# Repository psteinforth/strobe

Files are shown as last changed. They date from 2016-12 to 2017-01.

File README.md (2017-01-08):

# strobe
ATtiny microcontroller project to control a cheap stroboscope or similar device. 

### Introduction
This piece of software was designed to enable a cheap LED stroboscope by people on a danceflor. The strobe flashes as long as it is powered. The idea was to enable the strobe for a fixed time period as soon as a dancer presses a red push-button. To avoid nearly continuous flashing due to drunken people :dancers: the strobe can not be reenabled before a configurable time period passed.

### Features
- Based on Atmel ATtiny 44A-PU microcontroller.
- Interrupt-driven recognition of push-button presses.
- Strobe activity time period is configurable by a potentiometer.
- Time period between two strobe activites is potentiometer controllable.
- Status LED for "push button active/ strobe can be enabled" and "strobe active".
- Automatic reset in case of a microcontroller hang-up by watchdog timer within 0.125 seconds.

### Details
- Some options are configurable by **preprocessor defines**. Default values will be used if they are not given. Meaning of preprocessor defines can be found in source code comments.
- Program sequence is controlled by a **Finite State Machine**
    - Legend (0 = no/not required, 1 = yes/required, -1 = unspecified/don't care)
        - buzzer_enabled (output): push-button is active and can enable the strobe
        - relais_enabled (output): relais is active and powers the strobe
        - buzzer_pressed (input): push-button was pressed
        - timer_counting (input): timer is active (strobe active or buzzer locked and time is not over)
        - next_state: new state that will be selected if all inputs met the current state
    - State transition matrix:

State | Name | buzzer_enabled | relais_enabled | buzzer_pressed | timer_counting | next_state
------|------|----------------|----------------|----------------|----------------|------------
S_0 | WAIT_FOR_KEYPRESS | 1 | 0 | 1 | -1 | BLINKING
S_1 | BLINKING | 0 | 1 | -1 | 0 | BUZZER_LOCKED
S_2 | BUZZER_LOCKED | 0 | 0 | -1 | 0 | WAIT_FOR_KEYPRESS

State transition diagram (arrows are labeled with inputs that are required for state change):
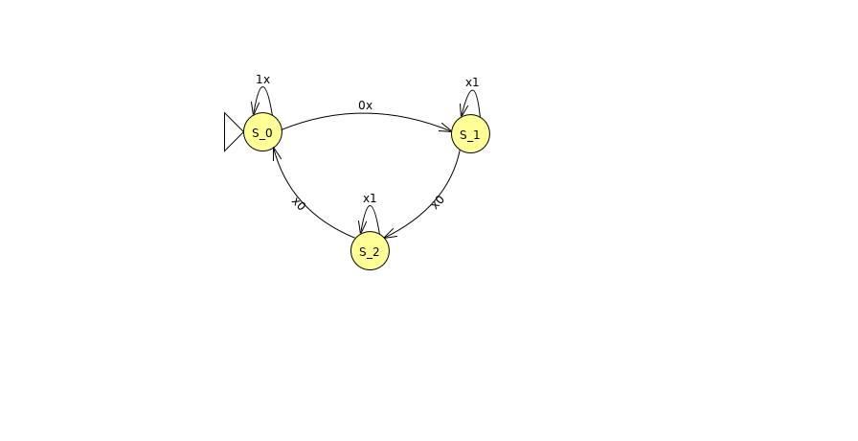
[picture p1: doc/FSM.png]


- All **time periods** are counted  by 16-bit Timer/Counter 1
- **Push-putton** presses are detected by external interrupt INT0
- **Potentiometers** are sampled by analog/digital converter (ADC)
    - Sampling is conducted only once after each power on/reset. So the adjustment of potentiometers is not detected until next microcontroller reset/restart.
    - This program does not use the low noise mode while sampling potentiometer values. However for better sampling results an averaged value of several (configurable by preprocessor define) samplings is calculated. In addition for every potentiometer an additional sampling is done first to stabilize the ADC, the value of this conversion is thrown.
- The circuit should be **power**ed with 5 V (DC). In other cases maybe other and/or additional components are required. It's recommended to enable the brown-out detector to reset the microcontroller if the current falls below a certain level (maybe 4.3 V).

### Microcontroller connections
Legend:
- *Italic* pins are required for In-System-Programming (ISP) via SPI. Pins printed grey additonally are only required for ISP.
- AREF is not connected but maybe will be used for more precise potentiometer values later. 
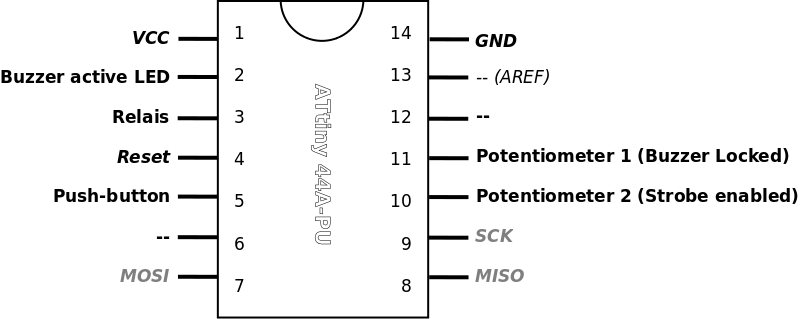
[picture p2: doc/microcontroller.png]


### Circuit Diagram
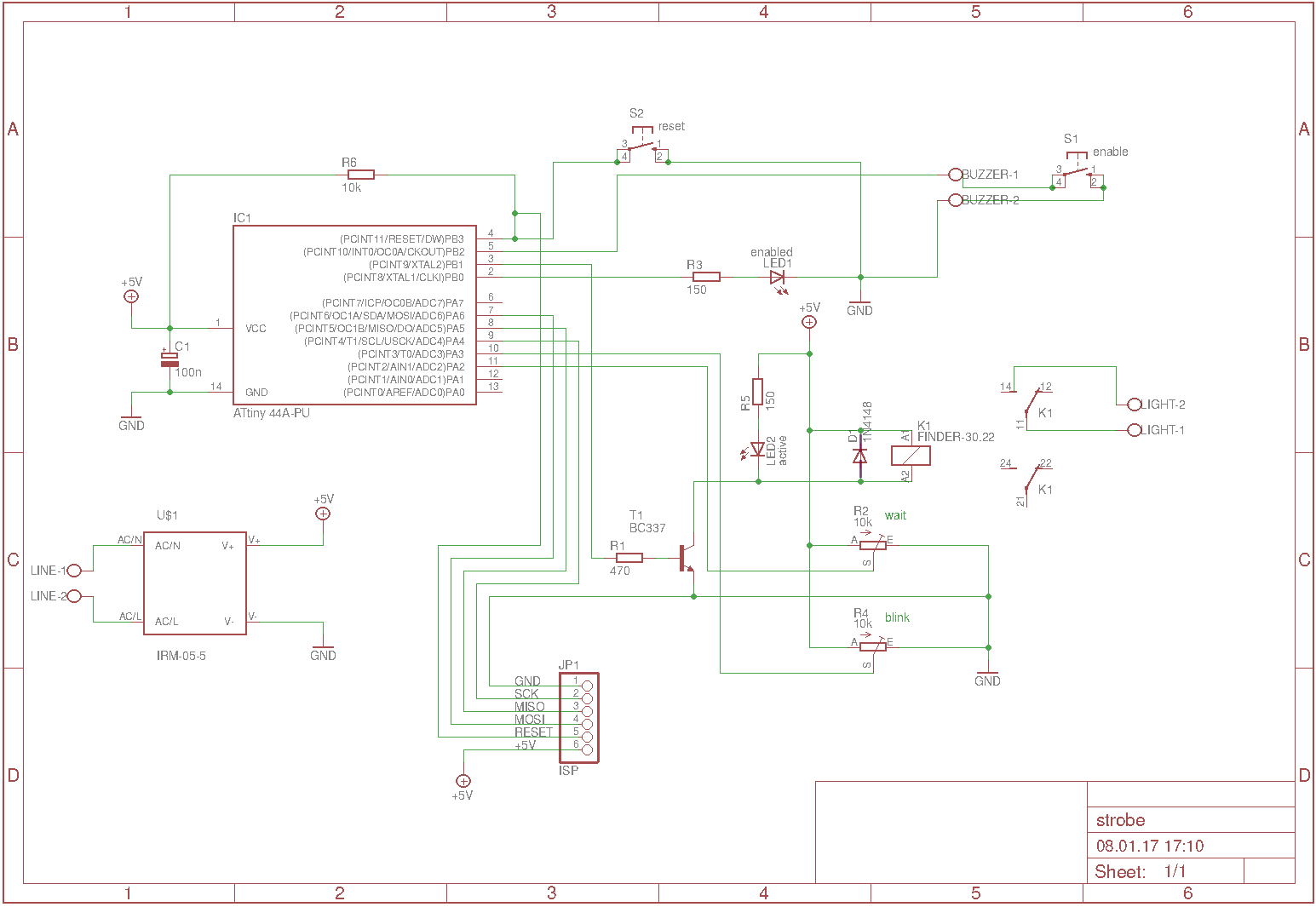
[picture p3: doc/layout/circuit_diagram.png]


### Conductor board example
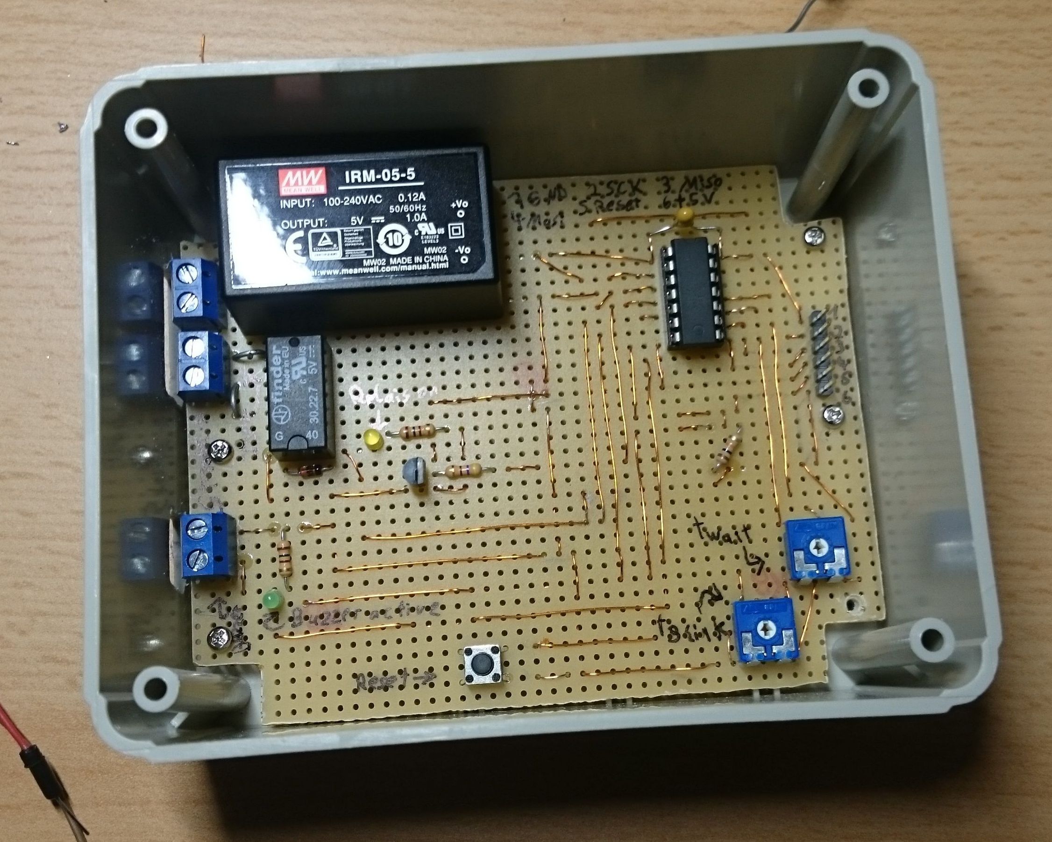
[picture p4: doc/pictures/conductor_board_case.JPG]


### Known issues
- __External Interrupt enabled unintentional.__
Under some circumstances (noisy environments) the external interrupt is triggered by electrical interferences. This maybe could be solved by implementing a debouncing algorithm to detect button presses and/or additonal hardware like external pull up resistors, a low pass filter or capacitors at the right place.

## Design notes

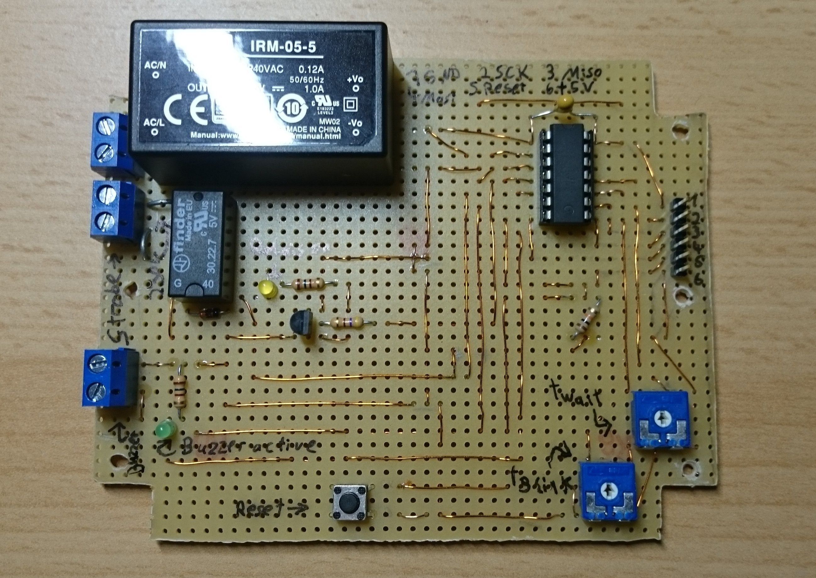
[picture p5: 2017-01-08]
doc/pictures/conductor_board.JPG

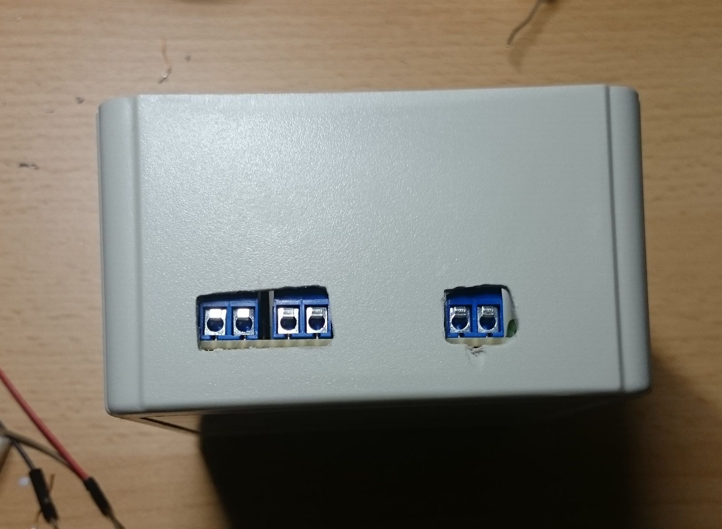
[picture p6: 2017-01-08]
doc/pictures/case_with_screw_terminals.JPG

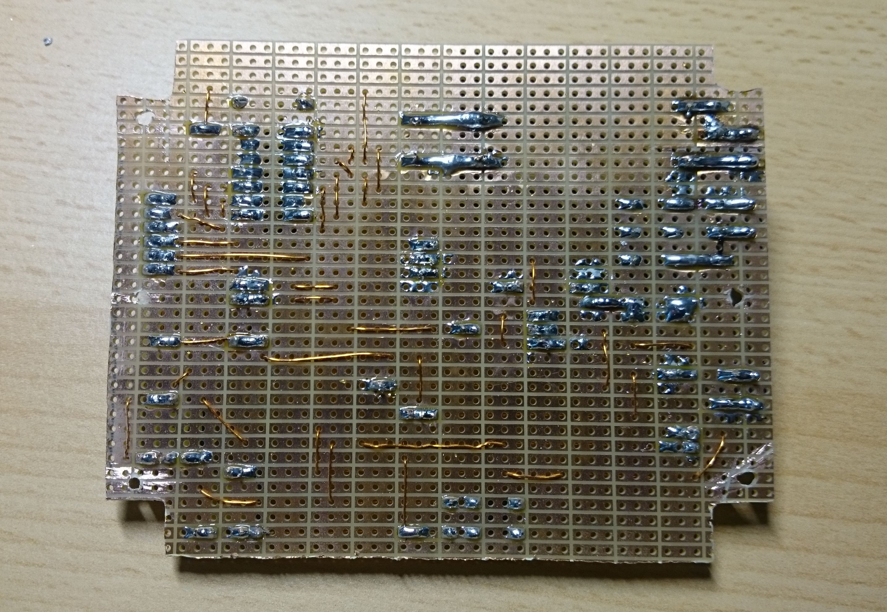
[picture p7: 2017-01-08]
doc/pictures/conductor_board_top_down.JPG

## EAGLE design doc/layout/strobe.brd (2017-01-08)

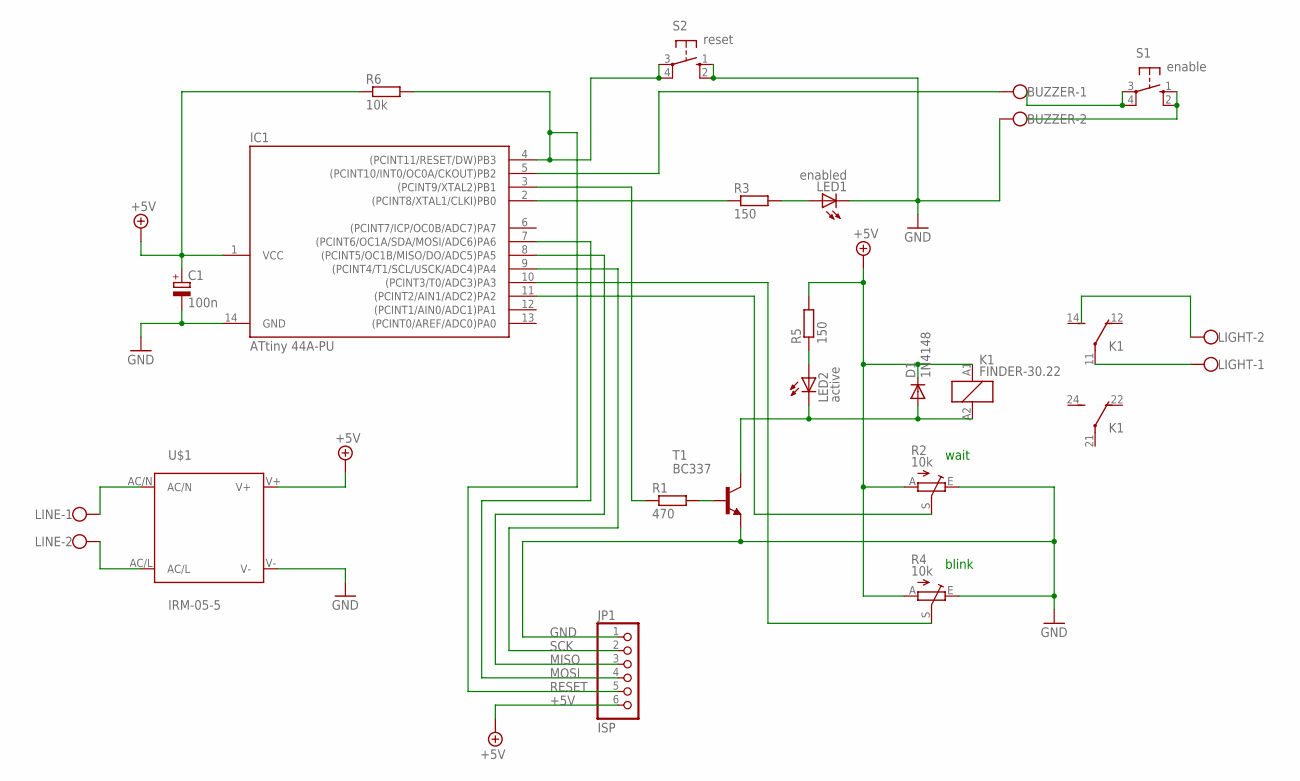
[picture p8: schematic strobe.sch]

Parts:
BUZZER: W237-102
C1: 100n; E2,5-6E
D1: 1N4148; DO35-7
IC1: ATtiny 44A-PU; DIL14
JP1: ISP; 1X06
K1: FINDER-30.22
LED1: enabled; LED3MM
LED2: active; LED3MM
LIGHT: W237-102
LINE: W237-102
R1: 470; 0207/10
R2, R4: 10k; CA6V
R3, R5: 150; 0207/10
R6: 10k; 0207/10
S1: enable; B3F-10XX
S2: reset; B3F-10XX
T1: BC337; TO92
U$1: IRM-05-5; IRM_05/10

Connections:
+5V: C1.+, D1.C, IC1.1 (VCC), JP1.6, K1.A1 (1), R2.A, R4.A, R5.2, R6.1
GND: BUZZER.2, C1.-, IC1.14 (GND), JP1.1, LED1.K (C), R2.E, R4.E, S2.1 (S), S2.2 (S1), T1.1 (E), U$1.V-
MISO: IC1.8 ((PCINT5/OC1B/MISO/DO/ADC5)PA5), JP1.3
MOSI: IC1.7 ((PCINT6/OC1A/SDA/MOSI/ADC6)PA6), JP1.4
unnamed: LINE.1, U$1.AC/N
unnamed: IC1.3 ((PCINT9/XTAL2)PB1), R1.1
unnamed: R1.2, T1.2 (B)
unnamed: IC1.11 ((PCINT2/AIN1/ADC2)PA2), R2.S
unnamed: IC1.10 ((PCINT3/T0/ADC3)PA3), R4.S
unnamed: D1.A, K1.A2 (2), LED2.K (C), T1.3 (C)
unnamed: LED1.A, R3.2
unnamed: IC1.2 ((PCINT8/XTAL1/CLKI)PB0), R3.1
unnamed: BUZZER.1, IC1.5 ((PCINT10/INT0/OC0A/CKOUT)PB2)
unnamed: K1.11, LIGHT.1
unnamed: LED2.A, R5.1
unnamed: S1.1 (S), S1.2 (S1)
unnamed: S1.3, S1.4 (P1)
RESET: IC1.4 ((PCINT11/RESET/DW)PB3), JP1.5, R6.2, S2.3, S2.4 (P1)
SCK: IC1.9 ((PCINT4/T1/SCL/USCK/ADC4)PA4), JP1.2

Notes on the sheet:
blink
wait

Board: 2 copper layers, 20 parts (0 on the bottom side), 19 nets, no tracks yet.

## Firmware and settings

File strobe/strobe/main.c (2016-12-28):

/*
 * main.c
 *
 * Created: 22.12.2016 19:00:13
 * Author : Patrick Steinforth (dev@steinforth.eu)
 */ 

#include <avr/io.h>
#include <avr/interrupt.h>
#include <inttypes.h> //int8_t and similar datatypes
#include <avr/wdt.h> //watchdog

#ifndef F_CPU
/* Define CPU frequency F_CPU if F_CPU was not already defined 
   (e.g. by command line parameter for compiler within 
   a Makefile). Warn if no frequency was passed by parameter. */
#warning "F_CPU was not defined and will be set to 1MHz"
#define F_CPU 1000000UL     /* Internal oscillator with 1.0000 MHz (prescaled by 8) */
#endif

#ifndef F_TIMER_INT
/* Define how often Timer1 Interrupt service routine is called 
   (e.g. by command line parameter for compiler within 
   a Makefile). Warn if no frequency was passed by parameter. */
#warning "F_TIMER_INT was not defined and will be set to 256"
#define F_TIMER_INT 256UL     /* Interrupt called every 1000/F_TIMER_INT= x milliseconds */
#endif
#if F_TIMER_INT > 256
#error "F_TIMER_INT must be in the range between 1 and 256 because we use a 8 bit variable."
#endif
#if F_TIMER_INT < 1
#error "F_TIMER_INT must be in the range between 1 and 256 because we use a 8 bit variable."
#endif

#ifndef TIMER_PRESCALER
/* Set hardware prescaler of timer 
   (e.g. by command line parameter for compiler within 
   a Makefile). Warn if no prescaler was passed by parameter. 
   Value has to match the timer/counter configuration. */
#warning "TIMER_PRESCALER was not defined and will be set to 1"
#define TIMER_PRESCALER 1UL     /* Timer counts every TIMER_PRESCALER clock cycle */
#endif

#ifndef ADC_AVERAGE_STEPS
/* Define from how much analog digital conversions the average will be calculated. */
#warning "ADC_AVERAGE_STEPS was not defined and will be set to 3"
#define ADC_AVERAGE_STEPS 3
#endif
#if ADC_AVERAGE_STEPS > 31
#error "ADC_AVERAGE_STEPS must be in the range between 1 and 31 so we can use one single 8 bit variable for all ADC[1:7] pins."
#endif
#if ADC_AVERAGE_STEPS < 1
#error "ADC_AVERAGE_STEPS must be in the range between 1 and 31 so we can use one single 8 bit variable for all ADC[1:7] pins."
#endif

#ifndef MAX_BLINKING_TIME
/* Define the maximum blinking time in seconds. This value will be set if potentiometer is in maximum position. */
#warning "MAX_BLINKING_TIME was not defined and will be set to 20"
#define MAX_BLINKING_TIME 20
#endif
#if MAX_BLINKING_TIME > 255
#error "MAX_BLINKING_TIME must be in the range between 1 and 255."
#endif
#if MAX_BLINKING_TIME < 1
#error "MAX_BLINKING_TIME must be in the range between 1 and 255."
#endif

#ifndef MAX_BUZZER_LOCKED_TIME
/* Define the maximum buzzer blocking time in TENs of seconds. This value will be set if potentiometer is in maximum position. 
Example: A value of 37 results in a lock time of 37*10=370 seconds = 5 minutes 10 seconds*/
#warning "MAX_BUZZER_LOCKED_TIME was not defined and will be set to 2"
#define MAX_BUZZER_LOCKED_TIME 2
#endif
#if MAX_BUZZER_LOCKED_TIME > 255
#error "MAX_BUZZER_LOCKED_TIME must be in the range between 1 and 255."
#endif
#if MAX_BUZZER_LOCKED_TIME < 1
#error "MAX_BUZZER_LOCKED_TIME must be in the range between 1 and 255."
#endif

#ifndef MAX_BUZZER_LOCKED_ADJUSTMENT
/* Define the maximum time range by which the buzzer lock time can be adjusted with potentiometer
 in TENs of seconds. If MAX_BUZZER_LOCKED_TIME is greater than MAX_BUZZER_LOCKED_ADJUSTMENT, the
 buzzer lock time can be adjusted in the interval from 
 (MAX_BUZZER_LOCKED_TIME - MAX_BUZZER_LOCKED_ADJUSTMENT) to MAX_BUZZER_LOCKED_TIME. This makes it
 easier to control the buzzer lock time with the potentiometer to the correct value.
Example: MAX_BUZZER_LOCKED_TIME = 45 (450 seconds), MAX_BUZZER_LOCKED_ADJUSTMENT = 30 (300 seconds).
 This results in a buzzer lock time interval from 15 (150 seconds) to 45 (450 seconds) that can be
 selected by potentiometer.*/
#warning "MAX_BUZZER_LOCKED_ADJUSTMENT was not defined and will be set to 30"
#define MAX_BUZZER_LOCKED_ADJUSTMENT 30
#endif
#if MAX_BUZZER_LOCKED_ADJUSTMENT > 255
#error "MAX_BUZZER_LOCKED_ADJUSTMENT must be in the range between 1 and 255."
#endif
#if MAX_BUZZER_LOCKED_ADJUSTMENT < 1
#error "MAX_BUZZER_LOCKED_ADJUSTMENT must be in the range between 1 and 255."
#endif


#define MAX_ADC_VALUE 256
//Maximum value of ADC conversion. 256 because of 8 bit resolution.

#define OC_MATCH_VAL ((F_CPU / (TIMER_PRESCALER * F_TIMER_INT)) -1) 
/* We count F_TIMER_INT times to the above calculated value. After that, one second is gone. Ok, this
is not completely correct, we have to account for a divisions remainder in the last step. This will
calculated next. We subtract 1 because timer period equals output compare register plus one.*/
#define REMAINDER (F_CPU % (TIMER_PRESCALER * F_TIMER_INT))

#if (OC_MATCH_VAL+REMAINDER) > 65535
#error "Configuration would result in overflow of timer/counter register. Increase F_TIMER_INT or TIMER_PRESCALER."
#endif

//#define LED_BUZZER_ACTIVE PORTB0
//#define BUZZER PORTB2

typedef enum {WAIT_FOR_KEYPRESS=0, BLINKING, BUZZER_LOCKED} state_t;
	
typedef struct {//0 = false/no, 1 = true/yes, -1 = don't care
	//Outputs
	int8_t buzzer_enabled; //(LED)
	int8_t relais_enabled;
	//Inputs / requirements for state transition
	int8_t buzzer_pressed;
	int8_t timer_counting;
	//Next state
	state_t next_state;
	} strobe_state_t;

uint8_t volatile counter_seconds = 0;
uint8_t volatile counter_minutes = 0;
int8_t volatile buzzer_was_pressed = 0;
uint8_t volatile trimmer_BLINKING = 128;
uint8_t volatile trimmer_BUZZER_LOCKED = 128;

//Interrupt Service Routine for INT0
ISR(EXT_INT0_vect)
{
	buzzer_was_pressed = 1;
	GIMSK &= ~(1 << INT0); //turn interrupt off, so we do not have to debounce the push-button
}

//Interrupt Service Routine for timer 1 compare matches
ISR(TIM1_COMPA_vect)
{
	    static uint8_t prescaler=(uint8_t)F_TIMER_INT;

	    if( --prescaler == 0 ) {
		    prescaler = (uint8_t)F_TIMER_INT;                             
		    if( --counter_seconds <= 0 )                       
			{
				if (counter_minutes > 0)
				{
					counter_minutes--;
					counter_seconds = 59;
				}
				else
				{//we are done
					TCCR1B &= ~(1 << CS12 | 1<< CS11 | 1 << CS10); //disable timer/counter
					//TCNT1 = 0x0000; //clear counter (we use the clear timer on compare match mode)
				}
			}
#if REST==0												//if there is a remainder
	    }                                           
#else
	    OCR1A = OC_MATCH_VAL + REMAINDER;             // account for remainder in last call of ISR for every second
	    } else {
	    OCR1A = OC_MATCH_VAL;                    // use default value in any other cases
    }
#endif
}

ISR(ADC_vect)
{
	static uint8_t adc_iteration = 0;
	static uint16_t intermediate_result_BLINKING = 0;
	static uint16_t intermediate_result_BUZZER_LOCKED = 0;
	
	switch(adc_iteration / (ADC_AVERAGE_STEPS + 1)) //get conversion for ADC pin 0..(USED_ADC_PINS-1), plus 1 because the first conversion result will be discarded
	{
		case 0: // PA3 respectively ADC3
			if (adc_iteration % (ADC_AVERAGE_STEPS+1) == 0)
			{
				//First conversion result after ADC multiplexer change should be discarded
				intermediate_result_BLINKING = 0; //init temp variable
			}
			else
			{
				intermediate_result_BLINKING += ADCH;
			}
			if (1 * (ADC_AVERAGE_STEPS+1) -1 == adc_iteration)
			{
				// last iteration for this ADC pin
				trimmer_BLINKING = intermediate_result_BLINKING / ADC_AVERAGE_STEPS;
				ADMUX &= ~(1 << MUX5 | 1 << MUX4 | 1 << MUX3 | 1 << MUX2 | 1 << MUX1 | 1 << MUX0);
				ADMUX |= (1 << MUX1); //make conversion for other input next (ADC2)
			}
			ADCSRA |= (1 << ADSC); //do further conversion
			adc_iteration++;
			break;
		case 1: // PA2 respectively ADC2
			if (adc_iteration % (ADC_AVERAGE_STEPS+1) == 0)
			{
				//First conversion result after ADC multiplexer change should be discarded
				intermediate_result_BUZZER_LOCKED = 0; //init temp variable
			}
			else
			{
				intermediate_result_BUZZER_LOCKED += ADCH;
			}
			if (2 * (ADC_AVERAGE_STEPS+1) -1 == adc_iteration)
			{
				// last iteration for this ADC pin
				trimmer_BUZZER_LOCKED = intermediate_result_BUZZER_LOCKED / ADC_AVERAGE_STEPS;
				ADMUX &= ~(1 << MUX5 | 1 << MUX4 | 1 << MUX3 | 1 << MUX2 | 1 << MUX1 | 1 << MUX0);
				ADMUX |= (1 << MUX1 | 1 << MUX0); //make conversion for other input next (ADC3)
				
				//all ADC-pin values calculated. Re-init some variables, for the case that a new conversion will be started.
				adc_iteration = 0;
				ADCSRA &= ~(1 << ADEN); //turn ADC off
			}
			else
			{
				adc_iteration++;
				ADCSRA |= (1 << ADSC); //do further conversion
			}
			break;
		default:
			adc_iteration++;
		//should never be reached
	}
}


void init(void)
{
	//TODO: = instead of |= is enough, if init() is only called after a microcontroller reset because in that case I/O register include default values (0 in most cases)
	
	//Setup external interrupt INT0
	MCUCR = (1 << ISC01); //look for falling edges
	GIMSK = (1 << INT0); //enable INT0 interrupt
	
	//Configure pins
	//PORTxn is input if DDxn = 0, output if DDxn = 1; 
	//if PORTxn = 1 and input => pull-up resistor activated
	//if pin configured as output then PORTxn determines high (1) or low (0) state
	//writing 1 to PINxn toggles value of PORTxn
	PORTB = (1 << PORTB2);
	PORTB |= (1 << PORTB3); //activate pull-up resistors for unused pins
	PORTA |= (1 << PORTA7 | 1 << PORTA6 | 1 << PORTA5 | 1 << PORTA4 | 1 << PORTA1 | 1 << PORTA0); //activate pull-up resistors for unused pins
	DDRB = (1 << DDB0 | 1 << DDB1);
	//_NOP(); //nop for synchronisation
	
	//Configure Timer1
	TCCR1B = (1 << WGM12); //clear timer on compare match
	OCR1A = OC_MATCH_VAL; //Set value for interrupt
	TIMSK1 = (1 << OCIE1A); //enable interrupt on compare match
	
	//Configure Analog Digital Converter
	DIDR0 = (1 << ADC3D | 1 << ADC2D); //Disable digital input to ADC pins (not required but reduces power consumption)
	ADMUX = (1 << MUX1 | 1 << MUX0); //Select ADC3 as input for ADC
	ADCSRB = (1 << ADLAR); //Left adjust conversion result (so it's possible to read the 8 most significant bits in a easy way, 10 bit resolution not required)
	ADCSRA = (1 << ADPS1 | 1 << ADPS0 | 1 << ADIE | 1 << ADEN | 1 << ADSC); //Set ADC prescaler to 8; enable ADC interrupt; enable ADC; start conversion
		
	WDTCSR = (1 << WDE | 1 << WDP1 | 1 << WDP0); // Enable watchdog with 16K watchdog oscillator (128 kHz) cycles --> 0.125s until reset. CPU cycles within 0.125s: 1000000/(1/0.125)=125000

	//Enable interrupts globally
	sei();
}

int main(void)
{	
	init();
	
	state_t fsm_state = WAIT_FOR_KEYPRESS;
	uint16_t adjustable_BUZZER_LOCKED_time = 0;
	
	strobe_state_t state_table[3] = {
	   // buzzer_enabled
	   // |   relais_enabled
	   // |   |   buzzer_pressed
	   // |   |   |   timer_counting
	   // |   |   |   |  next_state
		{ 1,  0,  1, -1, BLINKING}, //S_0 (WAIT_FOR_KEYPRESS)
		{ 0,  1, -1,  0, BUZZER_LOCKED}, //S_1 (BLINKING)
		{ 0,  0, -1,  0, WAIT_FOR_KEYPRESS}, //S_2 (BUZZER_LOCKED)
	};
	
    while (1) 
    {
		wdt_reset();

		if (state_table[fsm_state].buzzer_enabled)
		{
			PORTB |= (1 << PORTB0); 
		} 
		else
		{
			PORTB &= ~(1 << PORTB0); 
		}
		if (state_table[fsm_state].relais_enabled)
		{
			PORTB |= (1 << PORTB1);
		} 
		else
		{
			PORTB &= ~(1 << PORTB1);
		}
		
		if (
			!(
				(state_table[fsm_state].buzzer_pressed == -1 ) ||
				(state_table[fsm_state].buzzer_pressed == 1 && buzzer_was_pressed) ||
				(state_table[fsm_state].buzzer_pressed == 0 && !buzzer_was_pressed)
			)
		)
		{
			continue;
		}
		int8_t timer_is_running = TCCR1B & (1 << CS12 | 1 << CS11 | 1 << CS10);  //timer is active if at least one bit of CS12, CS11 or CS10 is set
		if (
			!(
				(state_table[fsm_state].timer_counting == -1 ) ||
				(state_table[fsm_state].timer_counting == 1 && timer_is_running) ||
				(state_table[fsm_state].timer_counting == 0 && !timer_is_running)
				)
			)
		{
			continue;
		}
						
		fsm_state = state_table[fsm_state].next_state;
		if (fsm_state == WAIT_FOR_KEYPRESS)
		{
			if (GIFR & (1 << INTF0))
			{
				GIFR = (1 << INTF0); //clear External Interrupt Flag
			}
			GIMSK = (1 << INT0); //enable external interrupt
		}
		if (fsm_state == BLINKING)
		{
			buzzer_was_pressed = 0;

			counter_seconds = (trimmer_BLINKING / (MAX_ADC_VALUE / MAX_BLINKING_TIME)) % 60;
			counter_minutes = (trimmer_BLINKING / (MAX_ADC_VALUE / MAX_BLINKING_TIME)) / 60;
			if (counter_minutes <= 0 && counter_seconds <= 0)
			{
				counter_seconds = 1; //at least 1 second in BLINKING state
			}
			//counter_minutes = 0;
			//counter_seconds = 2;
			TCCR1B |= (1 << CS10); //set prescaler to 1 and enable timer/counter
		}
		if (fsm_state == BUZZER_LOCKED)
		{		
			if (MAX_BUZZER_LOCKED_TIME > MAX_BUZZER_LOCKED_ADJUSTMENT)
			{
				adjustable_BUZZER_LOCKED_time = (uint16_t)(trimmer_BUZZER_LOCKED / (MAX_ADC_VALUE / (MAX_BUZZER_LOCKED_ADJUSTMENT * 10.0)));
			}
			else
			{
				adjustable_BUZZER_LOCKED_time = (uint16_t)(trimmer_BUZZER_LOCKED / (MAX_ADC_VALUE / (MAX_BUZZER_LOCKED_TIME * 10.0)));
			}

			if (MAX_BUZZER_LOCKED_TIME > MAX_BUZZER_LOCKED_ADJUSTMENT)
			{
				adjustable_BUZZER_LOCKED_time += ((uint16_t)(MAX_BUZZER_LOCKED_TIME - MAX_BUZZER_LOCKED_ADJUSTMENT)) * 10;
			}

			counter_seconds = (uint8_t)(adjustable_BUZZER_LOCKED_time % 60);
			counter_minutes = (uint8_t)(adjustable_BUZZER_LOCKED_time / 60);
			
			if (counter_minutes <= 0 && counter_seconds <= 0)
			{
				counter_seconds = 1; //at least 1 second in BUZZER_LOCKED state
			}

// 			counter_minutes = 10;
// 			counter_seconds = 35;

			TCCR1B |= (1 << CS10); //set prescaler to 1 and enable timer/counter
		}
		
    }
}

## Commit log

2016-12-25 working without any features and without push button debouncing
2016-12-25 fixed push button debouncing
    [main.c]
2016-12-28 turn ADC off after conversion
2016-12-28 new feature: buzzer locked interval configurable
    [main.c]
2017-01-07 add circuit diagram
    [strobe.brd, strobe.sch]
2017-01-08 update circuit diagram
    [strobe.brd, strobe.sch]
2017-01-08 update doc
    [strobe.brd, strobe.sch]
